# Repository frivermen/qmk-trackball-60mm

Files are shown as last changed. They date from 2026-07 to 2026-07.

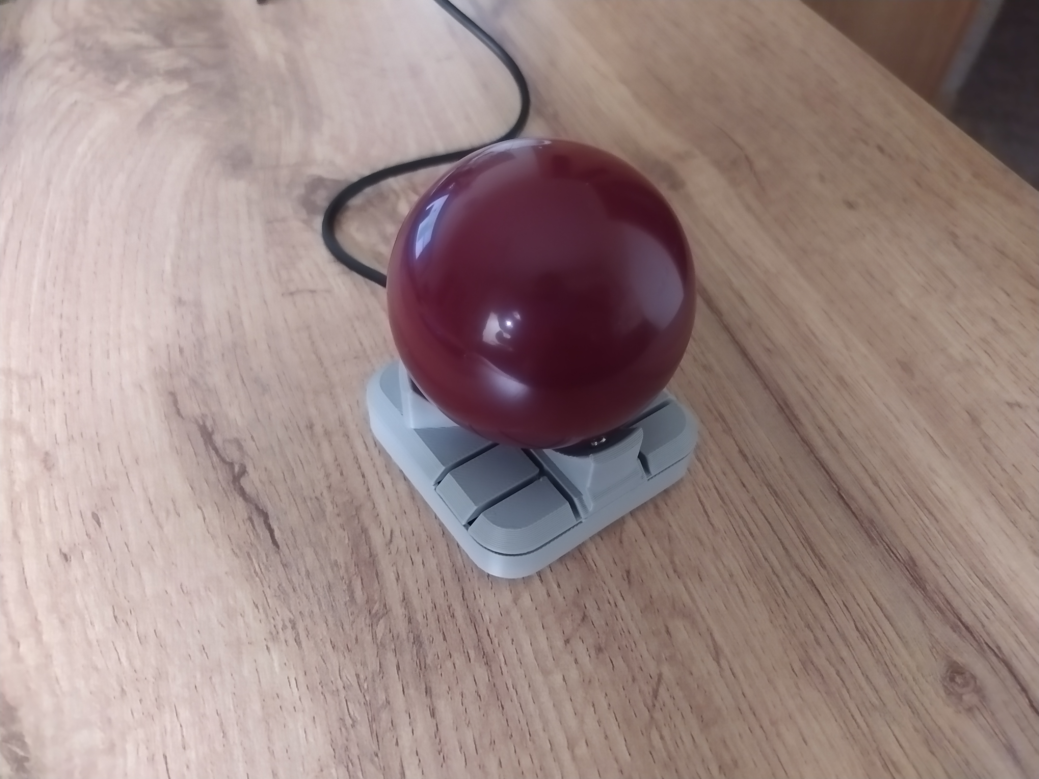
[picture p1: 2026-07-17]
photos/IMG_20260716_010455.jpg

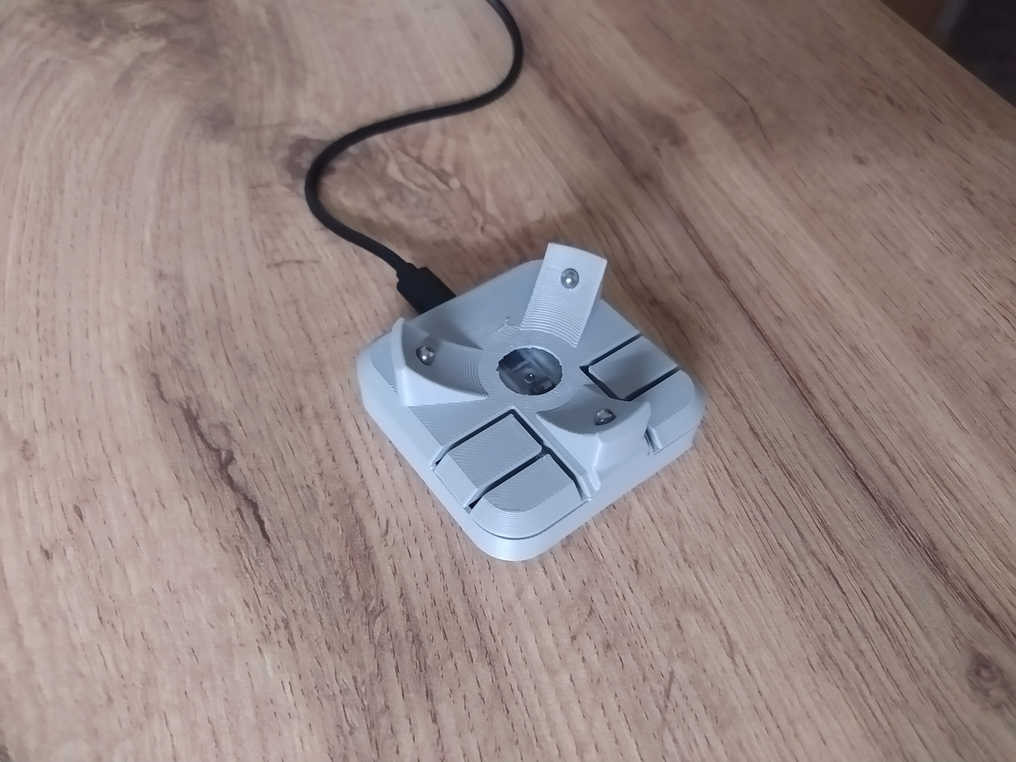
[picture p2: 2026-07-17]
photos/IMG_20260716_010500.jpg

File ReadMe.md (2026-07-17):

# Особенности
- Компактный корпус 60х60мм, при шаре 60мм.
- Сенсор LJFD3180C(PAW3204 совместимый)
- 4 кнопки: ЛКМ, СКМ, ПКМ, Скролл(высокого разрешения)

# История
Я захотел себе дешёвый, компактный трекбол с большим шаром. Купил на Озоне шар 60мм для бильярда и нашёл старую
беспроводную мышь, у которой потерялся донгл. Логическим анализатором сделал реверс-инжинеринг и выяснил что мой
сенсор LJFD3180C это копия PAW3204. Скидал скетч для esp32, проверил, что оно работает, заказал rpi pico, чтобы
поставить qmk прошивку как на Ploopy Adept. Спроектировал корпус и собрал. К сожалению фото внутри не сделал, но по
step файлу видно что да как. Кнопки впаял в макетную плату, а уже она на шуруп крепится, pico тоже на шурупы, а вот
сенсор я приклеил на термоклей, чтобы не делать свою плату. Просто отрезал лишнее от платы мыши и подпаял 4 провода.
Важное уточнение, я подключил 3.3в от pico к ljfd через диод с падением напряжения 0.7в, таким образом запитал его от
2.7в, это максимум по даташиту. SCK и DIO подключил напрямую, пока ничего не сгорело, но это не рекомендуется.

# Как пользоваться
Кнопка скролла по умолчанию работает в режиме переключения. Чтобы включить режим удержания, надо зажать Скрол+ПКМ.
Либо редактировать keymap.

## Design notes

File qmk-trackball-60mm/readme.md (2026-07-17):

# Frivermen Trackball

Самодельный трекбол на RP2040 с сенсором PAW3204 и 4 кнопками.

* Keyboard Maintainer: [frivermen](https://github.com/frivermen)
* Hardware Supported: RP2040, PAW3204 sensor
* Hardware Availability: DIY

## Сборка

    qmk compile -kb frivermen/trackball -km default

## Подключение

| Компонент | Пин RP2040 |
|---|---|
| PAW3204 SCK | GP6 |
| PAW3204 SDIO | GP7 |
| Кнопка 1 (ЛКМ) | GP16 |
| Кнопка 2 (СКМ) | GP15 |
| Кнопка 3 (ПКМ) | GP14 |
| Кнопка 4 (Скролл) | GP17 |

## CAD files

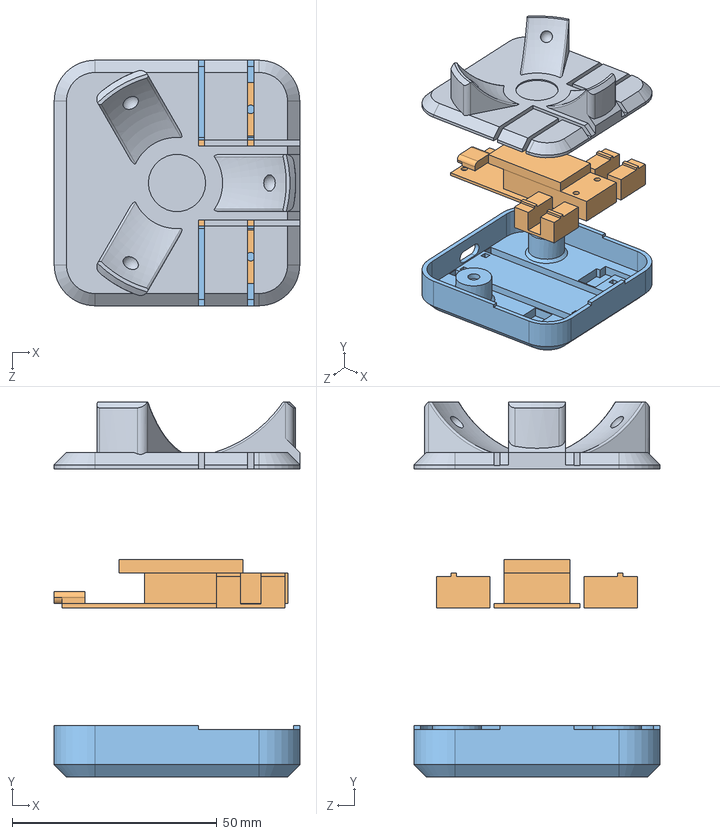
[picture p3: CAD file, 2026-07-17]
sw22-trackball-60mm/Сборка.SLDASM
60.0 x 91.6 x 60.0 mm
Стойка
Сенсор^Сборка4
Корпус^Сборка4

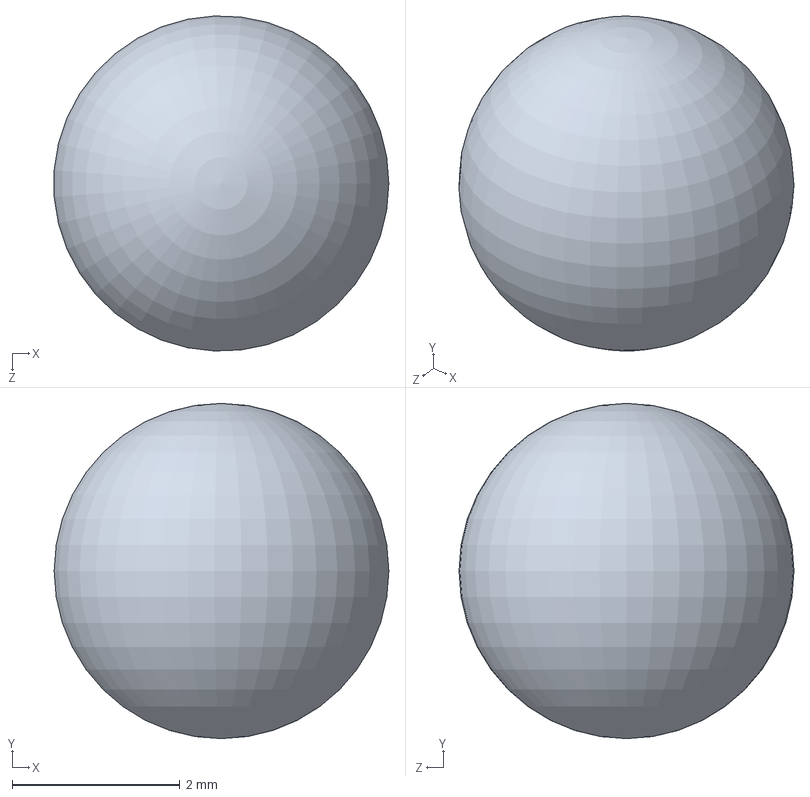
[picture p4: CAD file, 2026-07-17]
sw22-trackball-60mm/4mm.SLDPRT
3.99 x 4.00 x 4.00 mm

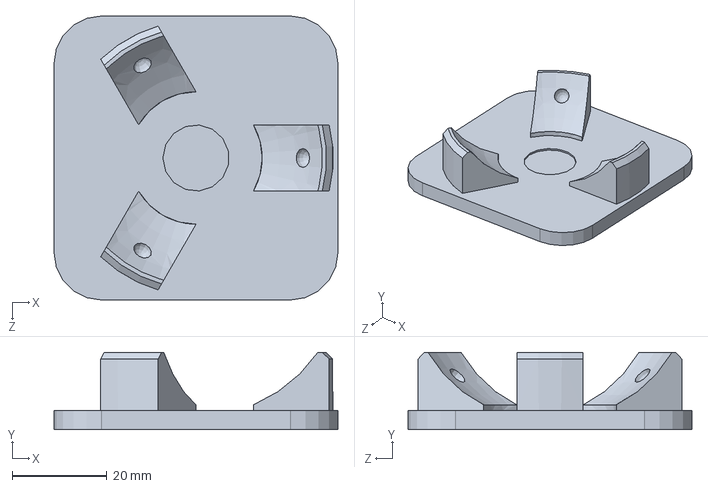
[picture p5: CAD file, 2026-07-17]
sw22-trackball-60mm/Стойка.SLDPRT
60.0 x 16.3 x 60.0 mm

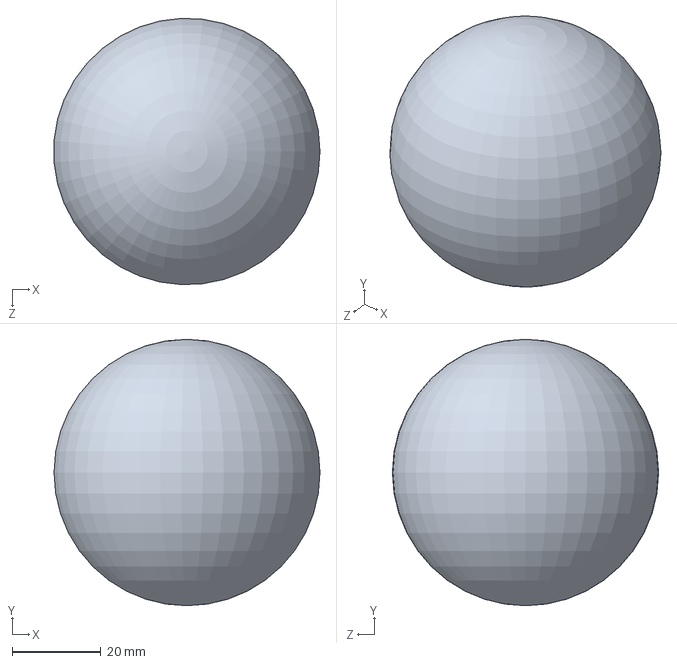
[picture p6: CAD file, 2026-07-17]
sw22-trackball-60mm/60mm.SLDPRT
59.9 x 60.0 x 60.0 mm

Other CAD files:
3d-model/trackball60mm.STEP

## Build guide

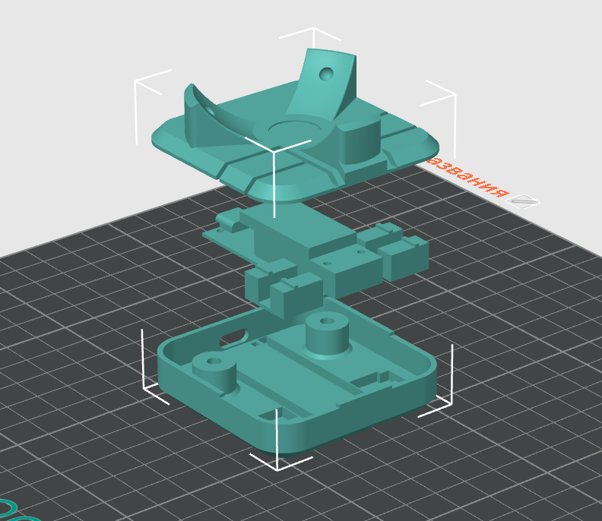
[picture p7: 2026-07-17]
photos/step-screenshot.png

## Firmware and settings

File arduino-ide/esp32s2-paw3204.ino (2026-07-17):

#include <Arduino.h>
#include <USB.h>
#include <USBHIDMouse.h>

// Пины для подключения к ESP32-S2 Mini
#define SCLK_PIN 37
#define SDIO_PIN 36

USBHIDMouse Mouse;

// ------------------------------------------------------------------
// Отправка одного байта (контроллер -> датчик)
// ------------------------------------------------------------------
void sendByte(uint8_t byte) {
  for (int i = 7; i >= 0; i--) {
    digitalWrite(SDIO_PIN, (byte >> i) & 0x01);
    digitalWrite(SCLK_PIN, HIGH);
    delayMicroseconds(1);
    digitalWrite(SCLK_PIN, LOW);
    delayMicroseconds(1);
  }
}

// ------------------------------------------------------------------
// Чтение одного байта (датчик -> контроллер)
// ------------------------------------------------------------------
uint8_t readByte() {
  uint8_t data = 0;
  pinMode(SDIO_PIN, INPUT_PULLUP);
  delayMicroseconds(1);
  for (int i = 7; i >= 0; i--) {
    digitalWrite(SCLK_PIN, HIGH);
    delayMicroseconds(1);
    if (digitalRead(SDIO_PIN)) {
      data |= (1 << i);
    }
    digitalWrite(SCLK_PIN, LOW);
    delayMicroseconds(1);
  }
  pinMode(SDIO_PIN, OUTPUT);
  return data;
}

// ------------------------------------------------------------------
// Запись в регистр
// ------------------------------------------------------------------
void writeRegister(uint8_t reg, uint8_t data) {
  pinMode(SDIO_PIN, OUTPUT);
  digitalWrite(SCLK_PIN, LOW);
  sendByte(reg | 0x80);
  sendByte(data);
}

// ------------------------------------------------------------------
// Чтение регистра
// ------------------------------------------------------------------
uint8_t readRegister(uint8_t reg) {
  pinMode(SDIO_PIN, OUTPUT);
  digitalWrite(SCLK_PIN, LOW);
  sendByte(reg & 0x7F);
  return readByte();
}

// ------------------------------------------------------------------
// Инициализация
// ------------------------------------------------------------------
void setup() {
  Serial.begin(115200);
  delay(1000);
  Serial.println("\n=== PAW3204 USB HID Mouse ===");

  // Настройка пинов
  pinMode(SCLK_PIN, OUTPUT);
  digitalWrite(SCLK_PIN, LOW);
  pinMode(SDIO_PIN, OUTPUT);
  digitalWrite(SDIO_PIN, HIGH);

  delay(100);

  // Проверка связи – чтение Product_ID1
  uint8_t pid = readRegister(0x00);
  Serial.printf("Product_ID1 = 0x%02X %s\n", pid, (pid == 0x30) ? "OK" : "ERROR");

  // Настройка разрешения 1600 CPI (пример)
  // Configuration: биты 2..0 = CPI, 0b110 = 1600
  writeRegister(0x06, 0b00000110);
  // Настройка качества при котором можно работать, 0~255
//  writeRegister(0x09, 0x5A); // write protect disable
//  writeRegister(0x0D, 20); // def 10
//  writeRegister(0x09, 0x00); // write protect enable
  Serial.printf("Configuration set to 0x%02X\n", readRegister(0x06));

  // Инициализация USB HID
  USB.begin();
  Mouse.begin();
  Serial.println("USB HID Mouse ready, polling rate 250 Hz");
}

void loop() {
  static uint32_t nextTime = 0;
  uint32_t now = micros();

  if (now >= nextTime) {
    nextTime = now + 4000;   // 4 мс = 250 Гц

    // Читаем статус движения
    uint8_t motion = readRegister(0x02);

    int8_t dx = 0, dy = 0;
    if (motion & 0x80) {               // бит Motion = 1
      dx = (int8_t)readRegister(0x03);
      dy = (int8_t)readRegister(0x04);
      // Можно добавить фильтрацию или масштабирование, если нужно
    }

    // Отправляем отчёт мыши (относительное перемещение)
//    Mouse.move(0, 0, -dy/4,/ dx/4); // scroll
    Mouse.move(dx, dy, 0, 0);
  }
}
